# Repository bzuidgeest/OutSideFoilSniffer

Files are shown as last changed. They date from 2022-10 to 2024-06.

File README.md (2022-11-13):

This is a PCB design for the outside foil tester as presented and designed by the YouTube channel RestoreOldRadios. I don't like prototyping PCB's so I made a "real" one. I don't do that to often so it's a nice exercise in using Kicad.

Everything seems to be working fine for the smaller value capacitors. but at "larger" values the detected signal gets to low for the Arduino to measure. And larger is 0.1uF and more. Also I found that capacitors with the cardboard tubes and the modern yellow ones test fine. But I also have vintage ones using a plastic tube as a housing. That type also doesn't measure. Might be that the plastic is to much of an insulator

Some Obligatory pictures:

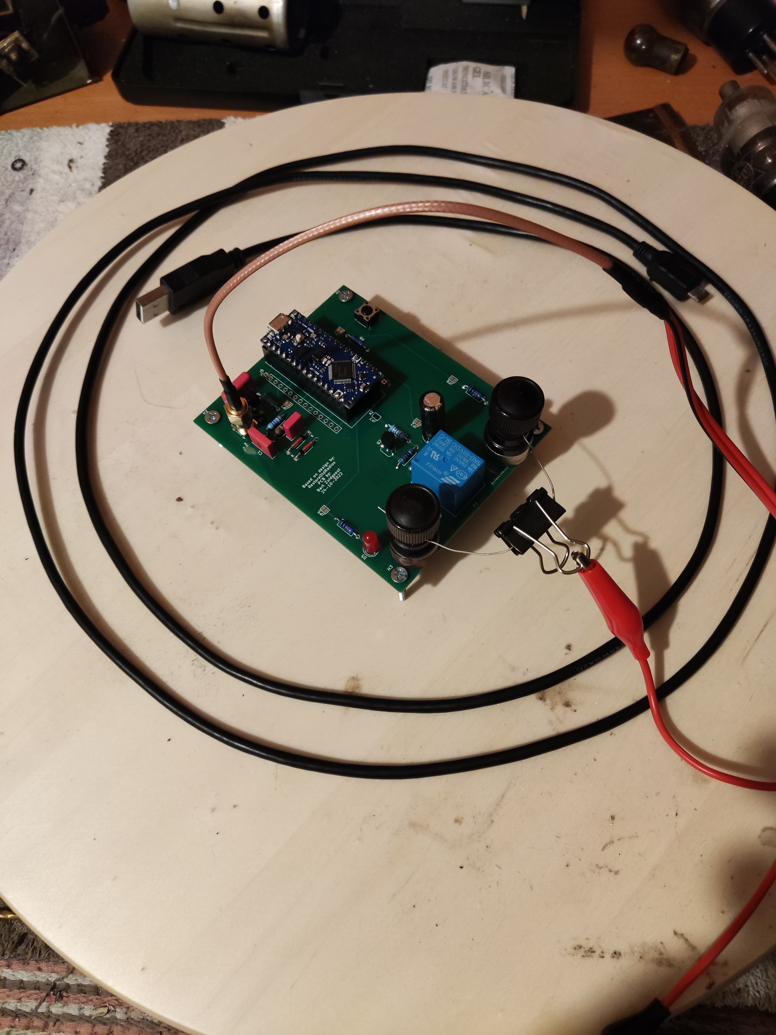
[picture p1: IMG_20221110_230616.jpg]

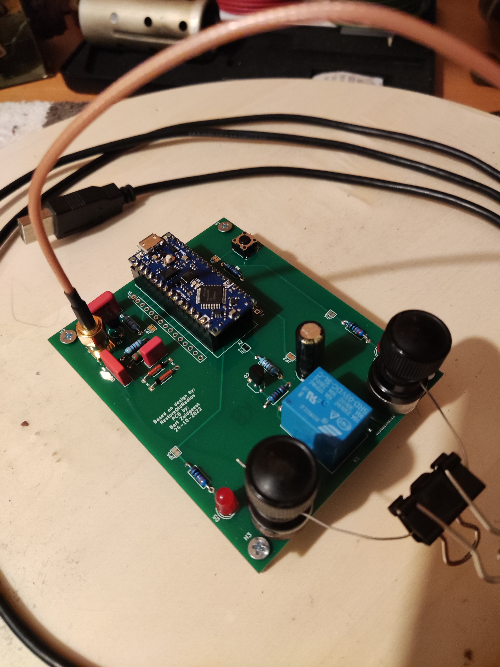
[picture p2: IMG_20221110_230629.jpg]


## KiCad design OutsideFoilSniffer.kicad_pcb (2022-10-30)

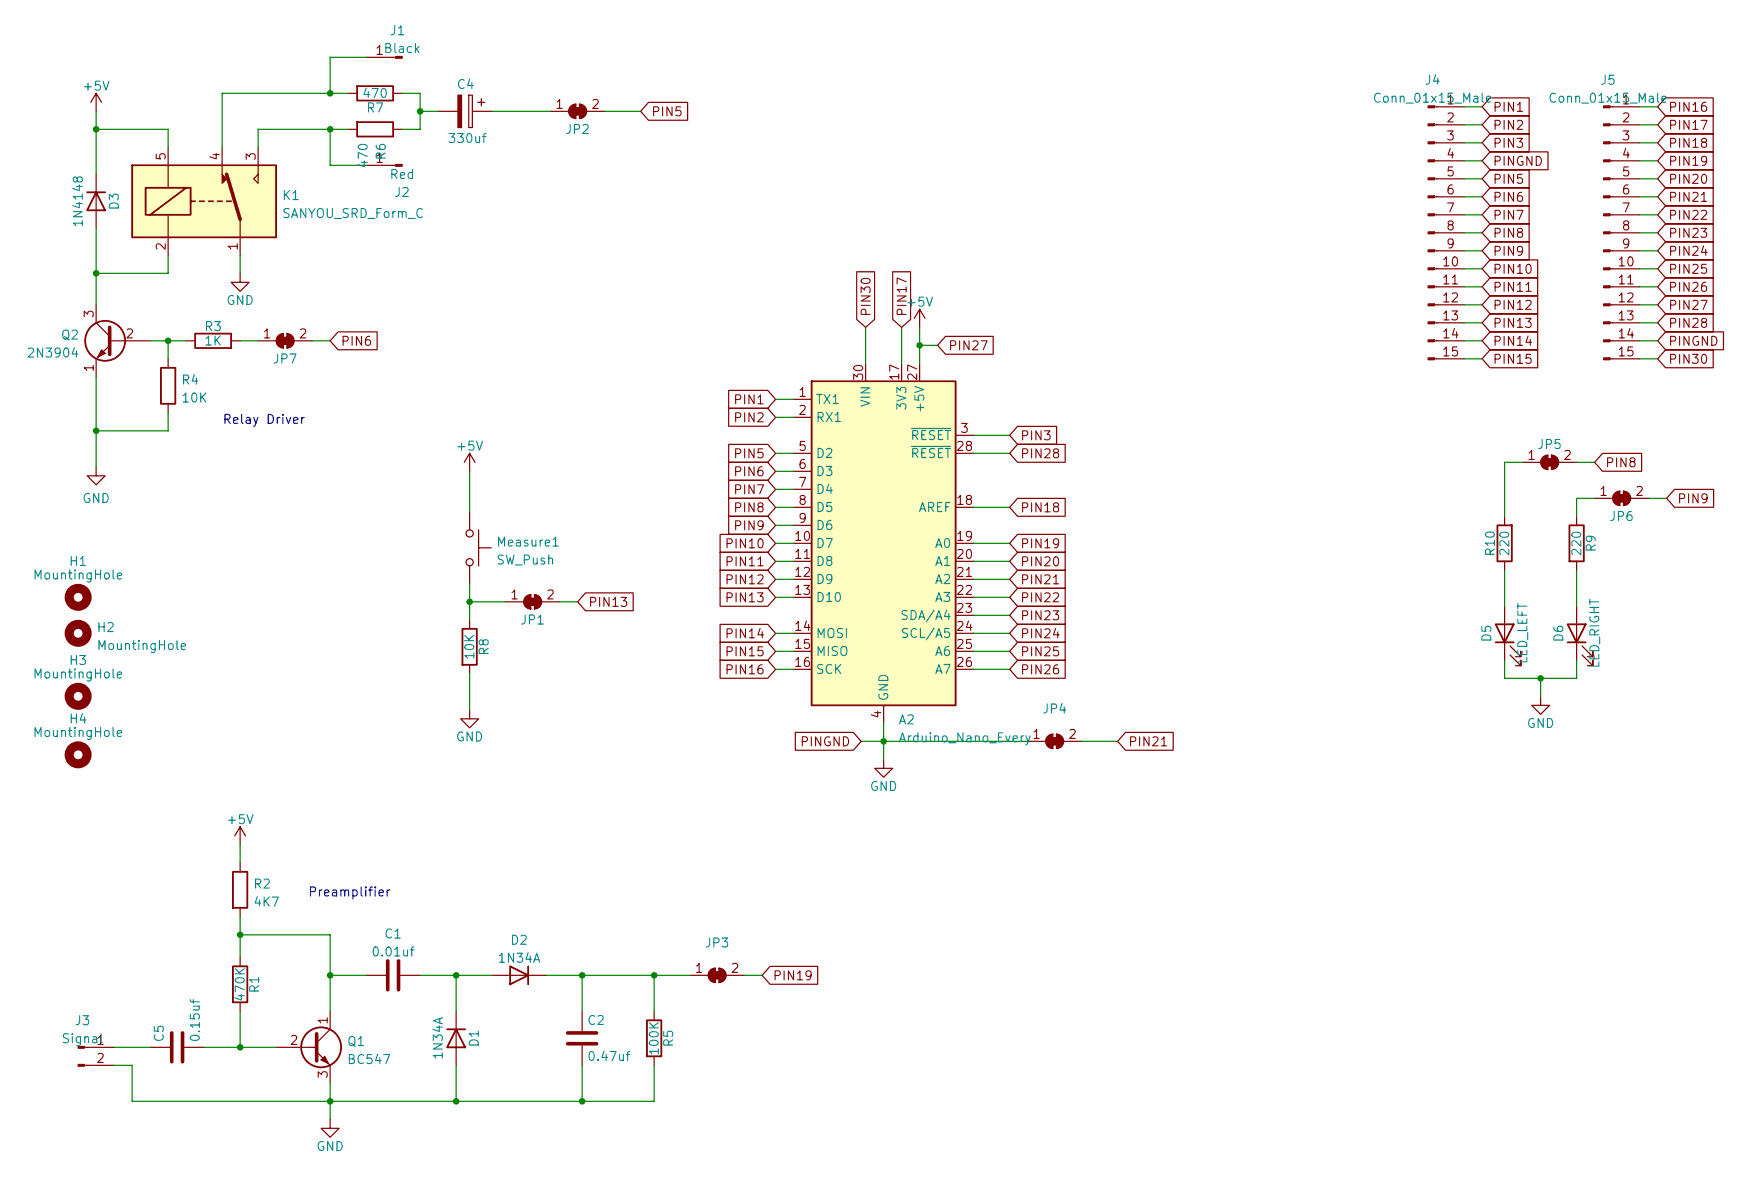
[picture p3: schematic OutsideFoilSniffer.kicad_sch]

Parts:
A2: Arduino_Nano_Every; Arduino_Nano
C1: 0.01uf; C_Rect_L10.0mm_W3.0mm_P7.50mm_MKS4
C2: 0.47uf; C_Rect_L7.0mm_W2.5mm_P5.00mm
C4: 330uf; CP_Radial_D8.0mm_P5.00mm
C5: 0.15uf; C_Rect_L13.0mm_W4.0mm_P10.00mm_FKS3_FKP3_MKS4
D1, D2: 1N34A; D_DO-35_SOD27_P10.16mm_Horizontal
D3: 1N4148; D_DO-35_SOD27_P7.62mm_Horizontal
D5: LED_LEFT; LED_D5.0mm
D6: LED_RIGHT; LED_D5.0mm
H1, H2, H3, H4: MountingHole; MountingHole_3.2mm_M3
J1: Black; Banana_Jack_1Pin
J2: Red; Banana_Jack_1Pin
J3: Signal; SMA_Amphenol_901-144_Vertical
J4, J5: Conn_01x15_Male; PinHeader_1x15_P2.54mm_Vertical
JP1, JP2, JP3, JP4, JP5, JP6, JP7: SolderJumper-2_P1.3mm_Bridged_Pad1.0x1.5mm
K1: SANYOU_SRD_Form_C; Relay_SPDT_SANYOU_SRD_Series_Form_C
Measure1: SW_Push; SW_PUSH_6mm
Q1: BC547; TO-92_Inline_Wide
Q2: 2N3904; TO-92_Inline_Wide
R1: 470K; R_Axial_DIN0207_L6.3mm_D2.5mm_P10.16mm_Horizontal
R2: 4K7; R_Axial_DIN0207_L6.3mm_D2.5mm_P10.16mm_Horizontal
R3: 1K; R_Axial_DIN0207_L6.3mm_D2.5mm_P10.16mm_Horizontal
R4, R8: 10K; R_Axial_DIN0207_L6.3mm_D2.5mm_P10.16mm_Horizontal
R5: 100K; R_Axial_DIN0207_L6.3mm_D2.5mm_P10.16mm_Horizontal
R6, R7: 470; R_Axial_DIN0207_L6.3mm_D2.5mm_P10.16mm_Horizontal
R9, R10: 220; R_Axial_DIN0207_L6.3mm_D2.5mm_P10.16mm_Horizontal

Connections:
unnamed: C1.1, D1.1 (K), D2.2 (A)
unnamed: C1.2, Q1.1 (C), R1.1, R2.2
unnamed: C2.1, D2.1 (K), JP3.1 (A), R5.1
unnamed: C4.1, JP2.1 (A)
unnamed: C4.2, R6.1, R7.1
unnamed: C5.1, J3.1
unnamed: C5.2, Q1.2 (B), R1.2
unnamed: D3.2 (A), K1.2, Q2.3 (C)
unnamed: D5.2 (A), R10.1
unnamed: D6.2 (A), R9.2
unnamed: J1.1, K1.4, R7.2
unnamed: J2.1, K1.3, R6.2
unnamed: JP1.1 (A), Measure1.2, R8.1
unnamed: JP5.1 (A), R10.2
unnamed: JP6.1 (A), R9.1
unnamed: JP7.1 (A), R3.2
unnamed: Q2.2 (B), R3.1, R4.2
PIN1: A2.1 (TX1), J4.1
PIN2: A2.2 (RX1), J4.2
PIN3: A2.3 (~RESET), J4.3
PIN5: A2.5 (D2), J4.5, JP2.2 (B)
PIN6: A2.6 (D3), J4.6, JP7.2 (B)
PIN7: A2.7 (D4), J4.7
PIN8: A2.8 (D5), J4.8, JP5.2 (B)
PIN9: A2.9 (D6), J4.9, JP6.2 (B)
PIN10: A2.10 (D7), J4.10
PIN11: A2.11 (D8), J4.11
PIN12: A2.12 (D9), J4.12
PIN13: A2.13 (D10), J4.13, JP1.2 (B)
PIN14: A2.14 (MOSI), J4.14
PIN15: A2.15 (MISO), J4.15
PIN16: A2.16 (SCK), J5.1
PIN17: A2.17 (3V3), J5.2
PIN18: A2.18 (AREF), J5.3
PIN19: A2.19 (A0), J5.4, JP3.2 (B)
PIN20: A2.20 (A1), J5.5
PIN21: A2.21 (A2), J5.6, JP4.2 (B)
PIN22: A2.22 (A3), J5.7
PIN23: A2.23 (SDA/A4), J5.8
PIN24: A2.24 (SCL/A5), J5.9
PIN25: A2.25 (A6), J5.10
PIN26: A2.26 (A7), J5.11
PIN27: A2.27 (+5V), D3.1 (K), J5.12, K1.5, Measure1.1, R2.1
PIN28: A2.28 (~RESET), J5.13
PIN30: A2.30 (VIN), J5.15
PINGND: A2.4 (GND), A2.29 (GND), C2.2, D1.2 (A), D5.1 (K), D6.1 (K), J3.2, J4.4, J5.14, JP4.1 (A), K1.1, Q1.3 (E), Q2.1 (E), R4.1, R5.2, R8.2

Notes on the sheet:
Preamplifier
Relay Driver

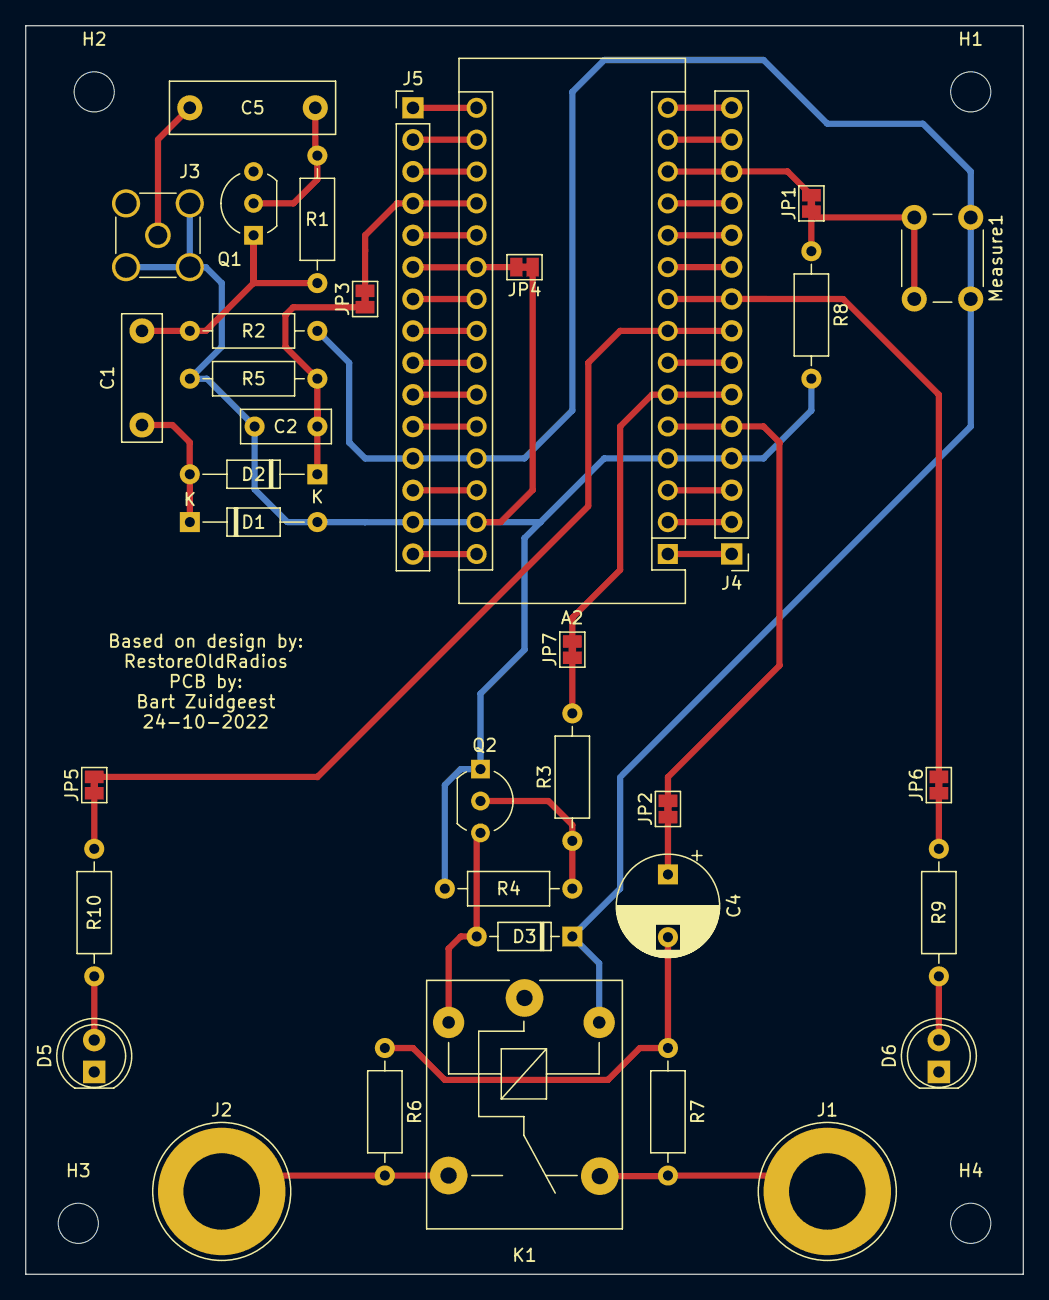
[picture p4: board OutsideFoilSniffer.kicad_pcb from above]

Board: 2 copper layers, 79.5 x 99.5 mm, 40 parts (0 on the bottom side), 46 nets.

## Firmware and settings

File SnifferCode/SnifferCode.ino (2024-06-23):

// pin assignments
int pinButton = 10;  // defines D10 for pullup button switch
int pinRelay = 3;
int pinLedLeft = 5;
int pinLedRight = 6;
int pinSquareWave = 2;  // defines D2 for square wave output signal

int stateButton;
int previous = LOW;
long time = 0;
long debounce = 500;  // default of 500 ms works well
int stayON = 1000;    // keeps relay on (HIGH) for 1000 ms or 1 second faster switching might be acceptable.

//int resetADC;  // A2 grounded to reset ADC
float freq = 15.0;  // 15KHz default square wave frequency in kHz for testing the capacitors

void setup() {
  pinMode(pinButton, INPUT);  // defines D10 as an INPUT to activate the button switch
  pinMode(pinRelay, OUTPUT);  // defines D3 as an OUTPUT to control the relay

  pinMode(pinLedLeft, OUTPUT);   // defines D5 as an OUTPUT to drive the right facing LED
  pinMode(pinLedRight, OUTPUT);  // defines D6 as an OUTPUT to drive the left facing LED

  Serial.begin(9600);

  Serial.print("Test Frequency: ");
  Serial.print(freq);
  Serial.println(" kHz");

  tone(pinSquareWave, freq * 1000);
}

void loop() {

  stateButton = digitalRead(pinButton);
  if (stateButton == HIGH && previous == LOW & millis() - time > debounce) {

    // Print a message
    Serial.println("Testing...");

    // Clear leds
    digitalWrite(pinLedLeft, LOW);   // D6 off - (left LED)
    digitalWrite(pinLedRight, LOW);  // D5 on - (right LED)

    //turn on relais
    digitalWrite(pinRelay, HIGH);

    // Let things stabilise
    delay(stayON);

    // Clear ADC -> is this really needed?
    // Measure signal strength
    float voltageA0 = analogRead(A0) * (5.0 / 1023.0);
    Serial.print("Value0: ");
    Serial.println(voltageA0, 4);

    // turn off relais
    digitalWrite(pinRelay, LOW);  // D13 off

    // Let things stabilise
    delay(stayON);

    // Measure signal strength
    float voltageA1 = analogRead(A0) * (5.0 / 1023.0);
    Serial.print("Value1: ");
    Serial.println(voltageA1, 4);

    if (voltageA0 != 0.0 || voltageA1 != 0.0) {
      // Show the result.
      if (voltageA0 > voltageA1) {
        digitalWrite(pinLedLeft, LOW);    // D6 off - (left LED)
        digitalWrite(pinLedRight, HIGH);  // D5 on - (right LED) to indicate Foil Side of Capacitor
      } else if (voltageA0 < voltageA1) {
        digitalWrite(pinLedLeft, HIGH);  // D6 on - (left LED) to indicate Foil Side of Capacitor
        digitalWrite(pinLedRight, LOW);  // D5 off - (right LED)
      } else if (voltageA0 == voltageA1) {
        digitalWrite(pinLedLeft, HIGH);   // D6 on - (left LED)
        digitalWrite(pinLedRight, HIGH);  // D5 on - (right LED) 
      }
    } else {
      // Something measured as zero. Do we have good connections?
      Serial.println("Both measurements are zero");
      digitalWrite(pinLedLeft, LOW);   // D6 off - (left LED)
      digitalWrite(pinLedRight, LOW);  // D5 on - (right LED) to indicate Foil Side of Capacitor
    }

    time = millis();
  }
  previous == stateButton;
}

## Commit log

2022-10-12 first draft, need to check package sizes
    [OutsideFoilSniffer.kicad_pcb, OutsideFoilSniffer.kicad_sch]
2022-10-24 Modified size to fit PCBWay prototype size 100x80 mm for cheap price
    [OutsideFoilSniffer.kicad_pcb, OutsideFoilSniffer.kicad_sch]
2022-10-24 minor changes
    [OutsideFoilSniffer.kicad_pcb]
2022-10-29 Added sniffer code modified for my design. Code needs serious cleanup
    [OutsideFoilSniffer.kicad_pcb, OutsideFoilSniffer.kicad_sch]
2024-06-23 Fix to code, now we have output when one of the leads reads zero
    [OutsideFoilSniffer.kicad_sch]
